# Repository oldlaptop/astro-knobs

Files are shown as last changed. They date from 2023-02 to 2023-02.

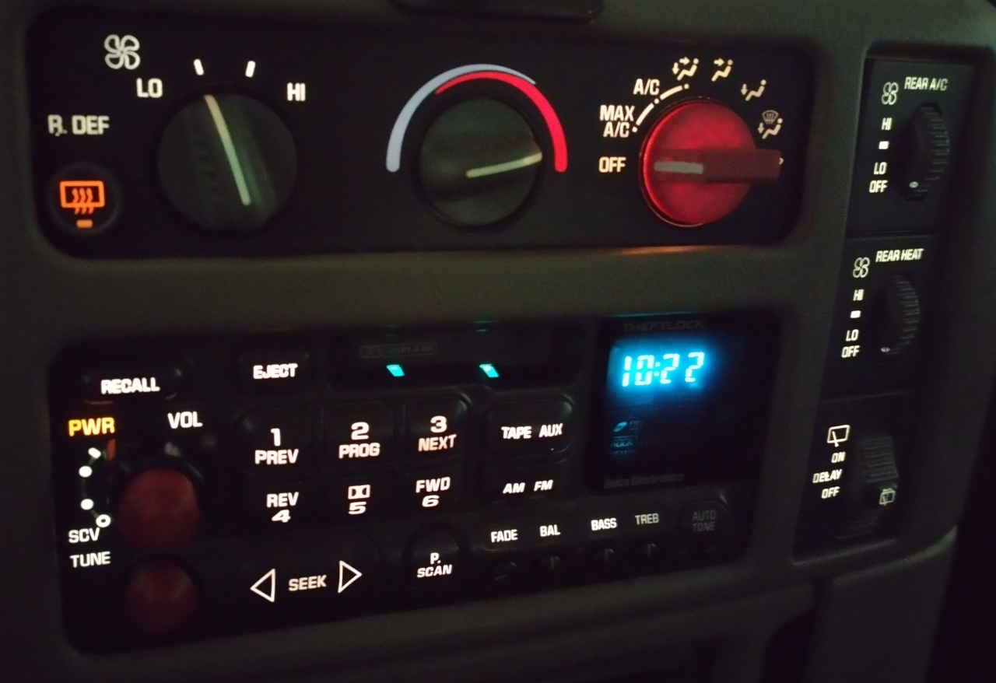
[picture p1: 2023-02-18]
sample-prints.jpg

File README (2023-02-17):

This repository contains OpenSCAD models of various interior control knobs for a
2004 Chevrolet Astro. For obvious reasons the selection is biased towards those
that tend to break at around ($PRESENT_YEAR - 2004) years. It seems likely that
at least some of these will fit other GM vehicles of the late '90s and early
'00s, probably biased towards the earlier end of that range (the Astro interior
was an old design by 2004). See comments in the individual source files for
details on what they are.

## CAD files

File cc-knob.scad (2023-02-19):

/*
 * Copyright (c) 2023 Peter Piwowarski <peterjpiwowarski@gmail.com>
 *
 * Permission to use, copy, modify, and distribute this model for any
 * purpose with or without fee is hereby granted, provided that the above
 * copyright notice and this permission notice appear in all copies.
 *
 * THE MODEL IS PROVIDED "AS IS" AND THE AUTHOR DISCLAIMS ALL WARRANTIES
 * WITH REGARD TO THIS MODEL INCLUDING ALL IMPLIED WARRANTIES OF
 * MERCHANTABILITY AND FITNESS. IN NO EVENT SHALL THE AUTHOR BE LIABLE FOR
 * ANY SPECIAL, DIRECT, INDIRECT, OR CONSEQUENTIAL DAMAGES OR ANY DAMAGES
 * WHATSOEVER RESULTING FROM LOSS OF USE, DATA OR PROFITS, WHETHER IN AN
 * ACTION OF CONTRACT, NEGLIGENCE OR OTHER TORTIOUS ACTION, ARISING OUT OF
 * OR IN CONNECTION WITH THE USE OR PERFORMANCE OF THIS MODEL.
 *
 * Climate-control knob (there are three that appear identical) for a 2004
 * Chevrolet Astro, and presumably other late-90s and early-2000s GM products
 * (particularly light trucks?). All measurements are in inches.
 *
 * On an FDM machine, I recommend placing the angled "nose" of the part facedown
 * on the print bed, which should allow the part to print with little or no
 * support. (I've tried using a tiny bit near where the fascia approaches the
 * print bed, where the overhang is steepest, but I don't think that did
 * anything.) Translucent material is suggested, given that the original knob is
 * illuminated.
 */

use <volume-knob.scad>

outer_dia = 1.250;
limiting_pin_x = 0.155;
limiting_pin_y = 0.085;
limiting_pin_z = 0.170;

// Distance from the outer rim of the knob to the outer edge of the limiting pin
limiting_pin_offset = 0.165;

/*
 * I did not end up modeling this narrow 'rim' around the back of the knob that
 * I carefully measured on the original; perhaps this was meant to keep light
 * from leaking around the edge?
rim_thickness = 0.050,
rim_depth = 0.035,
 */

rim_thickness = 0.050;
rim_depth = 0.035;

stem_od = 0.410;
stem_length = 0.450;

/*
 * These are very finicky, given that you want a tight friction fit - but not
 * one that requires enough force to break things - on a shaft that's about
 * 0.2in wide. Even the moisture content of PETG filament is believed to be able
 * to make the difference between too tight and too loose for the same stem_id
 * value. Planning to use the original metal liner may or may not make this more
 * forgiving, but will require modestly larger values.
 */
stem_id = 0.203;
stem_chord = 0.165;

fascia_thickness = 0.185;

grip_x = 0.33;
grip_y = outer_dia;
grip_z = 0.50;

$fn = 256;

module cc_knob(
	outer_dia = outer_dia,

	limiting_pin_x = limiting_pin_x,
	limiting_pin_y = limiting_pin_y,
	limiting_pin_z = limiting_pin_z,
	limiting_pin_offset = limiting_pin_offset,

	stem_od = stem_od,
	stem_length = stem_length,
	stem_id = stem_id,
	stem_chord = stem_chord,

	fascia_thickness = fascia_thickness,

	grip_x = grip_x,
	grip_y = outer_dia,
	grip_z = grip_z,
)
{
	union()
	{
		rotate([0, 0, 90])
		{
			/*
			 * In terms of the original volume knob's dimensions,
			 * the "length" is the distance from the back face of
			 * the knob to the top of the stem - zero in this case
			 * because there is no "well" in this knob as in the
			 * volume knob - and the "inset" is negative because the
			 * stem protrudes out from the back face of the knob,
			 * rather than being, well, set in to it.
			 */
			stem(
				total_height = 0,
				inset = -stem_length,
				id = stem_id,
				od = stem_od,
				flat = stem_chord
			);
		}
		limiting_pin();
		fascia();
		translate([0, 0, fascia_thickness])
		{
			grip();
		}
	}
}

module fascia(
	dia = outer_dia,
	thickness = fascia_thickness
)
{
	cylinder(h = thickness, d = dia);
}

module limiting_pin(
	x = limiting_pin_x,
	y = limiting_pin_y,
	z = limiting_pin_z,
	offs = ((outer_dia / 2) - limiting_pin_offset),
	pincolor = [0, 255/255, 0]
)
{
	cube_x = x - y;

	translate([0, -offs, -z])
	{
		color(pincolor)
		{
			translate([-cube_x / 2, 0, 0])
			{
				cube([cube_x, y, z]);
			}
			for (xsign = [+1, -1])
			{
				translate([xsign * cube_x / 2, y / 2, 0])
				{
					cylinder(h = z, d = y);
				}
			}
		}
	}
}

module grip(
	x = grip_x,
	y = grip_y,
	z = grip_z
)
{
	intersection()
	{
		translate([-(x / 2), -(y / 2), 0])
		{
			union()
			{
				polyhedron([
					[0, y, 0],
					[x, y, 0],
					[0, y - x, 0],
					[x, y - x, 0],
					[0, y - x, z],
					[x, y - x, z]
				], [
					[0, 2, 3, 1],
					[0, 1, 5, 4],
					[0, 4, 2],
					[1, 3, 5],
					[4, 5, 3, 2]
				]);
				cube([x, y - x, z]);
			}
		}
		cylinder(d = y, h = z);
	}
}

cc_knob();

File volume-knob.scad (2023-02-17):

/*
 * Copyright (c) 2021 Peter Piwowarski <peterjpiwowarski@gmail.com>
 *
 * Permission to use, copy, modify, and distribute this model for any
 * purpose with or without fee is hereby granted, provided that the above
 * copyright notice and this permission notice appear in all copies.
 *
 * THE MODEL IS PROVIDED "AS IS" AND THE AUTHOR DISCLAIMS ALL WARRANTIES
 * WITH REGARD TO THIS MODEL INCLUDING ALL IMPLIED WARRANTIES OF
 * MERCHANTABILITY AND FITNESS. IN NO EVENT SHALL THE AUTHOR BE LIABLE FOR
 * ANY SPECIAL, DIRECT, INDIRECT, OR CONSEQUENTIAL DAMAGES OR ANY DAMAGES
 * WHATSOEVER RESULTING FROM LOSS OF USE, DATA OR PROFITS, WHETHER IN AN
 * ACTION OF CONTRACT, NEGLIGENCE OR OTHER TORTIOUS ACTION, ARISING OUT OF
 * OR IN CONNECTION WITH THE USE OR PERFORMANCE OF THIS MODEL.
 *
 * Volume knob for the radio in a 2004 Chevrolet Astro (and surely other GM
 * factory radios from the late 1990s and early 2000s). All measurements are in
 * inches. (Fancy colors are meant solely to make troubleshooting the geometry a
 * bit easier.)
 *
 * On an FDM machine, I recommend printing with knob_chamfer = true, oriented
 * with the front of the knob facedown on the print bed. A brim is likely
 * necessary given the small contact patch.
 */

knob_height = 0.525; // Approximate overall height, including the rounded front
cyl_height = 0.400;  // Approximate height of the cylindrical section
knob_diameter = 0.691;

/*
 * If false, will render a spherical front profile like the original knob,
 * instead of an FDM-printer-friendly chamfer.
 */
knob_chamfer = true;
knob_chamfer_frac = 0.5; // 0 is no chamfer at all, 1 is a sharp-pointed cone

cutout_diameter = 0.500;             // Inside diameter of the cutout in the back
cutout_chamfer_max_diameter = 0.550; // Diameter of the chamfer at the far back
cutout_chamfer_depth = 0.059;        // Depth of the chamfer at its narrowest

/*
 * Internal diameter of the stem that fits on the radio's actuator. This
 * dimension is very sensitive, and appropriate values may depend on whether you
 * use the original metal 'liner' piece, and of course on your
 * particular printer, material, the phase of the moon, etc.
 */
stem_id = 0.202;

stem_od = 0.35;     // Adjust to suit printer and material, within reason
stem_inset = 0.170; // Distance between the back of the knob and the back of the stem
stem_flat = 0.190;  // Chord length of the flat portion on the inside of the stem

/*
 * Adjust to suit your printer's precision and/or your debugging tastes. This is
 * the result of "crank it up until I can't see the flats anymore", and probably
 * a tad excessive.
 */
$fn = 256;

module knob(
	knob_height = knob_height,
	cyl_height = cyl_height,
	knob_diameter = knob_diameter,

	knob_chamfer = true,
	knob_chamfer_frac = knob_chamfer_frac,

	cutout_diameter = cutout_diameter,
	cutout_chamfer_max_diameter = cutout_chamfer_max_diameter,
	cutout_chamfer_depth = cutout_chamfer_depth,

	stem_id = stem_id,
	stem_od = stem_od,
	stem_inset = stem_inset,
	stem_flat = stem_flat,
)
{
	union()
	{
		difference()
		{
			color("DarkGrey")
			{
				knob_outline(
					knob_height,
					cyl_height,
					knob_diameter,
					chamfer = knob_chamfer,
					chamfer_frac = knob_chamfer_frac
				);
			}
			color("HotPink")
			{
				knob_cutout(cyl_height, cutout_diameter, cutout_chamfer_depth, cutout_chamfer_max_diameter);
			}
		}
		stem(cyl_height, stem_inset, stem_id, stem_od, stem_flat);
	}
}

module knob_outline(overall_height, cyl_height, cyl_diameter, chamfer = false, chamfer_frac = 1)
{
	if (chamfer)
	{
		union()
		{
			cylinder(h = cyl_height, d = cyl_diameter);
			translate([0, 0, cyl_height])
			{
				cylinder(
					h = overall_height - cyl_height,
					d1 = cyl_diameter,
					d2 = cyl_diameter * chamfer_frac
				);
			}
		}
	} else
	{
		intersection()
		{
			cylinder(h = overall_height, d = cyl_diameter);
			sphere(overall_height);
		}
	}
}

module knob_cutout(height, diameter, chamfer_depth, chamfer_max_diameter)
{
	union()
	{
		translate([0, 0, -0.1])
		{
			cylinder(h = height + 0.1, d = diameter);
		}

		translate([0, 0, -chamfer_depth])
		{
			cylinder(
				h = chamfer_depth * 2,
				d1 = chamfer_max_diameter * 2 - diameter,
				d2 = diameter
			);
		}
	}
}

module stem(total_height, inset, id, od, flat, maincolor = [225/225, 0, 0])
{
	complementcolor = [1, 1, 1] - maincolor;
	meancolor = maincolor + complementcolor / 2;

	translate([0, 0, inset])
	{
		difference()
		{
			color(maincolor)
			{
				cylinder(h = total_height - inset, d = od);
			}
			color(complementcolor)
			{
				translate([0, 0, -0.1])
				{
					height = total_height - inset + 0.1;
					difference()
					{
						cylinder(h = height, d = id);
						color(meancolor)
						{
							translate([sqrt((id / 2) ^ 2 - (flat / 2) ^ 2), -(flat / 2), 0])
							{
								cube(size = [flat, flat, height]);
							}
						}
					}
				}
			}
		}
	}
}

knob();

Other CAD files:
tuner-knob.scad

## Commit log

2021-07-24 Initial, untested knob design
    [volume-knob.scad]
2021-07-24 chamfer option
    [volume-knob.scad]
2021-07-27 post-fitment tweak to stem inner diameter
    Not much chance of the rounded version working without extensive supports and
    (for single-extruder machines) the attendant surface-refinishing effort.
    [volume-knob.scad]
2021-07-27 Another minor fitment iteration: a bit tighter, and not so tall
    [volume-knob.scad]
2023-02-17 Add tuner and climate-control knob models, refactor
    Surely the van's control knobs will get tired of breaking soon, right?
    [cc-knob.scad, tuner-knob.scad, volume-knob.scad]
2023-02-18 fix formatting
    I could have sword I did this already
    [cc-knob.scad]
2023-02-19 Collection of post-fitment cc-knob corrections
    The indexing pin turns out to be off by pretty much exactly
    limiting_pin_y. (Oops.) I also reckon the grip could stand to be taller,
    and that there's no real need for the stem to be quite so long.
    stem_id really is *outrageously* touchy: 0.205 was on the very edge of
    "too small" for the first attempts, but after drying the filament a bit
    it's clearly too big.
    [cc-knob.scad]
